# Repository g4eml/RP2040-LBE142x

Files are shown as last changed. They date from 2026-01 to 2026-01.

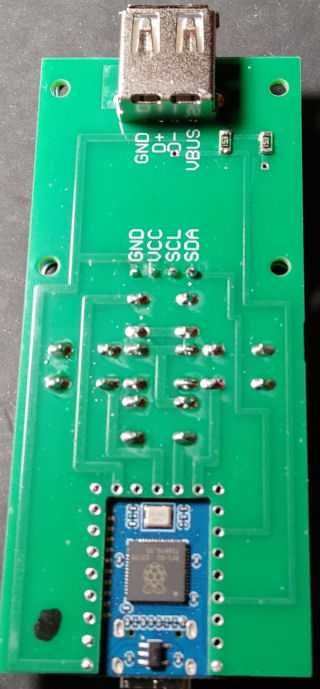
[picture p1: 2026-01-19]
BottomView.jpg

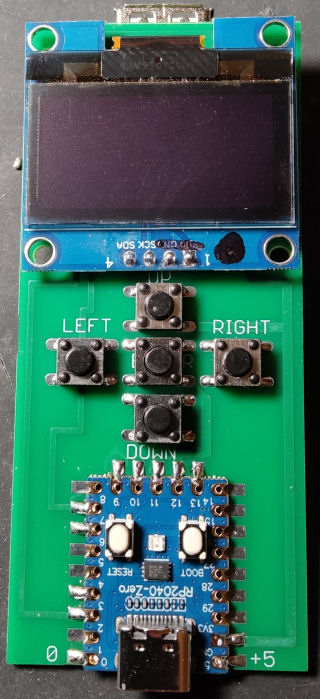
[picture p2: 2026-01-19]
TopView.jpg

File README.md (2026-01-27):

# RP2040_LBE142x

## Description

Stand alone programmer for the Leo Bodner LBE-1420 and LBE-1421 GPSDOs. 

## Features

Connects to LBE-1420 or LBE-1421 using USB. Allows the current frequencies of the unit to be changed without needing to be connected to a computer. 

100 memories to store regularly used frequencies. 

OLED display to show current frequency and memory contents. 

Memories can be changed using the 5 menu buttons. 

## Requirements

RP2040 Zero Module.  (other RP2040 modules can also be used, such as the Pico)

1.3" I2C OLED display (4 Pin type).  128 x 64 pixels single colour. Available from many sources. Try to get one with the SH1106 Controller chip.

**Warning...** These displays come from various manufacturers. There does not seem to be any standard for the pin layout. Check the VCC and GND pins match the PCB layout. 
Some versions of the display have configuration jumpers to swap the VCC and Ground Pins. Configure these so that Pin 1 is GND and Pin 2 is VCC. 

5 push button switches. (Tactile switches)

USB A PCB Mount Socket. 

2 15K resistors

## Construction

A PCB Design is included. The gerber files can be sent to any of the low cost PCB manufacturers. 

Note that the USB-A socket and the two 15K resistors are fitted on the bottom side of the PCB. The RP2040 Zero, Buttons and Display are all fitted on the top side. Make sure you fit the USB-A socket before the Display. 

Alternatively the design can easily be built on matrix board. 

This is the schematic. 

[Schematic.pdf](https://github.com/g4eml/RP2040-LBE142x/blob/main/Schematic.pdf)

Top View.
[Top View](https://github.com/g4eml/RP2040-LBE142x/blob/main/TopView.jpg)

Bottom View.
[Bottom View](https://github.com/g4eml/RP2040-LBE142x/blob/main/BottomView.jpg)

## Enclosure

A 3d printable enclosure is included in the 3D Print folder.  This consists of three parts, the main box, the endcap and the pushbuttons. Note that the holes in the main box are deliberately printed undersize. These need to be drilled out to 5mm diameter. This produces
neater holes than trying to print them directly. The display window can be cut out with a sharp knife. The pushbuttons should be left connected together, do not cut them apart.

## Programming or updating the RP2040 Zero Module (quick method)

1. Locate the latest compiled firmware file 'RP2040_LBE142x.uf2' which will be found here https://github.com/g4eml/RP2040-LBE142x/releases and save it to your desktop. 

2. Connect the Module to your PC using the USB-C port.. 

3. Hold down the BOOT button on the HMI module and briefly press the Reset button. The RP2040 should appear as a USB disk drive on your PC.

3. Copy the .uf2 file onto the USB drive. The RP2040 will recognise the file and immediately update its firmware and reboot.

## Building your own version of the firmware (longer method and not normally required)

The RP2040 is programmed using the Arduino IDE with the Earl F. Philhower, III  RP2040 core. 

#### Installing the Arduino IDE

1. Download and Install the Arduino IDE 2.3.0 from here https://www.arduino.cc/en/software

2. Open the Arduino IDE and go to File/Preferences.

3. in the dialog enter the following URL in the 'Additional Boards Manager URLs' field: https://github.com/earlephilhower/arduino-pico/releases/download/global/package_rp2040_index.json

4. Hit OK to close the Dialog.

5. Go to Tools->Board->Board Manager in the IDE.

6. Type “RP2040” in the search box.

7. Locate the entry for 'Raspberry Pi Pico/RP2040 by Earle F. Philhower, III' and click 'Install'

### Installing the required libraries

1. From the Arduino IDE select (Tools > Manage Libraries)
2. Search for 'Adafruit GFX' Scroll down to find the Adafruit GFX Library by Adafruit.
3. Click Install
4. Now search for 'Adafruit SH110X' and find the Adafruit SH110X library by Adafruit..
5. Click Install

#### Downloading the Software.

1. Download the latest released source code .zip file from https://github.com/g4eml/RP2040_LBE142x/releases

2. Save it to a convenient location and then unzip it.

#### Programming the RP2040

1. Open the Arduino IDE and click File/Open

2. Navigate to the File RP2404Synth/RP2040_LBE1421x.ino (downloaded in the previous step) and click Open.

3. Select Tools and make the following settings.

   Board: "Raspberry Pi Pico"
   
   Debug Level: "None"

   Debug Port: "Disabled"

   C++ Exceptions: "Disabled"

   Flash Size: "2Mb (no FS)"

   CPU Speed: "240MHz (Overclock)"   ........ Note the USB Host Mode only works with multiples of 120MHz for the clock. 240 MHz seems to work OK on most chips. 

   IP/Bluetooth Stack: "IPV4 Only"

   Optimise: "Small (-Os)(standard)"

   RTTI: "Disabled"

   Stack Protection: "Disabled"

   Upload Method: "Default (UF2)"

   USB Stack: "Adafruit TinyUSB"  

5. Connect the RP2040 Module to the USB port, hold down the BOOT button and briefly press the reset Button. 

6. Click Sketch/Upload.

The Sketch should compile and upload automatically to the RP2040. If the upload fails you may need to disconnect the module and then hold down the BOOT button while reconnecting. 

## Firmware description

When power is applied to the RP2040 USB-C socket the firmware will start and display "LBE-1420 Programmer  G4EML 2026"

Connect the LBE-142x to the USB A socket on the programmer.  After a few seconds it should be recognised and the display will show "LBE-1420 Connected" , the current Frequencies and the GPS Lock Status. 

To change the frequency press the Enter button. 
A new line will appear at the bottom of the display. " M00=  10.000000 MHz "  (note that on first use all memories will be initialised to 10.000000 MHz.)
The M00 part of the line will be underlined, indicating the Memory number can be changed. Do this with the Up or down buttons.
When connected to a LBE-1421 each press of the up or down button will cycle between F1 and F2 before changing the memory number. 
When you have selected the memory you require press the Enter button. The memory frequency will be transfered to the LBE-142x and the status lines at the top of the screen should show it has been accepted. 

To change the memory frequencies. 
Fist select the required memory using the Up and down bottons. 
For the LBE-1421 make sure you have also selected the correct output. 
Then press the right button to move the underline cursor to the first of the frequency digits (1000 Mhz).
Position the cursor on the required digit using the left and right buttons.
Change the digit using the Up and Down buttons. 
When you have selected the frequency you require press the Enter button. 
The frequency will be transfered to the LBE-142x and will also be saved to the RP2040 EEPROM for future use.

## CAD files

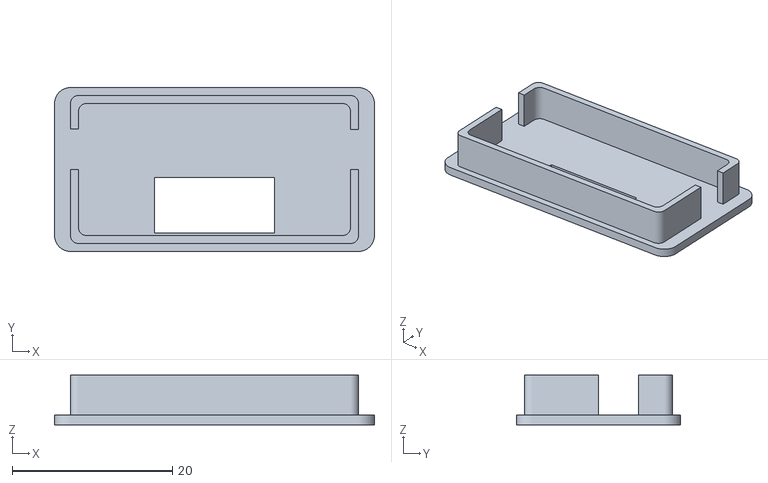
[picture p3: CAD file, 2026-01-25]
3D Print/V2/EndCap-Plus1.stl
40.0 x 20.5 x 6.19

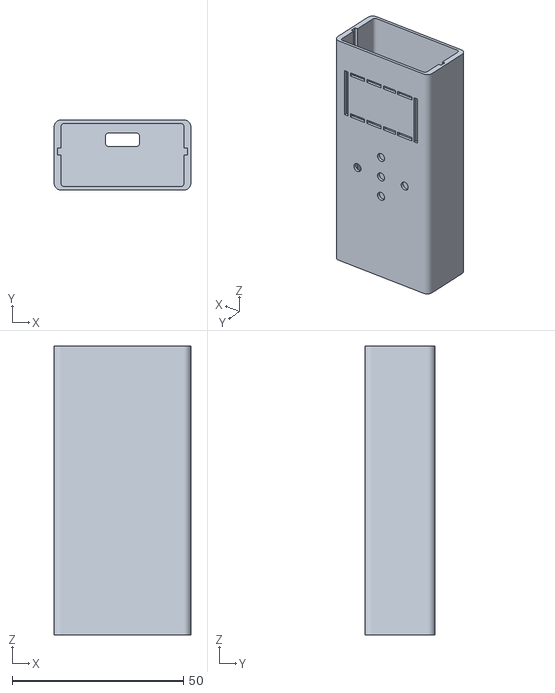
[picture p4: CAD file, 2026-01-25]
3D Print/V2/Box-Plus1.stl
40.0 x 20.5 x 84.5

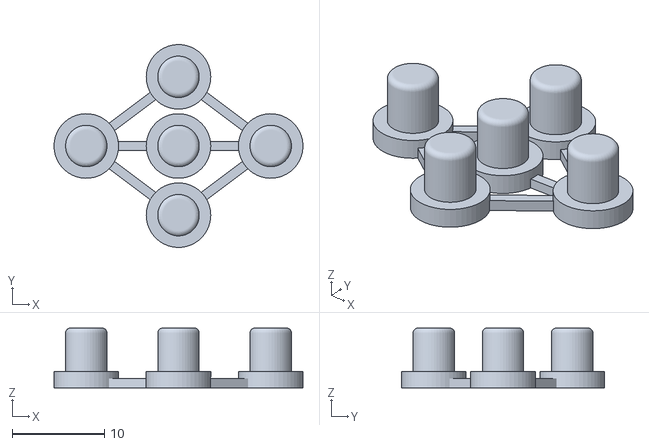
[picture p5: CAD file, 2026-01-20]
3D Print/V2/Buttons.stl
27.0 x 22.0 x 6.50

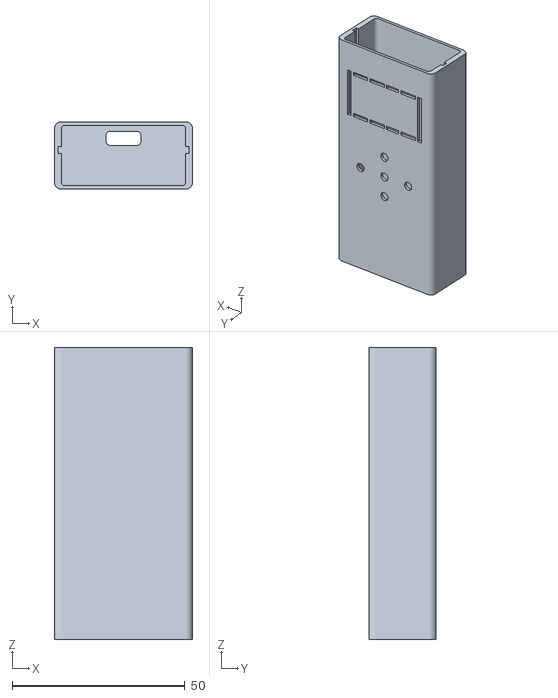
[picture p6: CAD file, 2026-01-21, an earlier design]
3D Print/V1/Box.stl
40.0 x 19.5 x 84.5

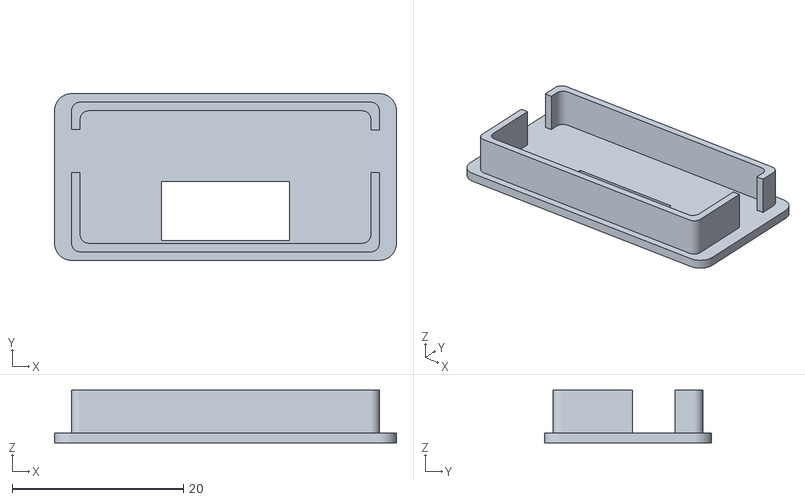
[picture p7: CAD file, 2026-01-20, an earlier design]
3D Print/V1/EndCap.stl
40.0 x 19.5 x 6.19

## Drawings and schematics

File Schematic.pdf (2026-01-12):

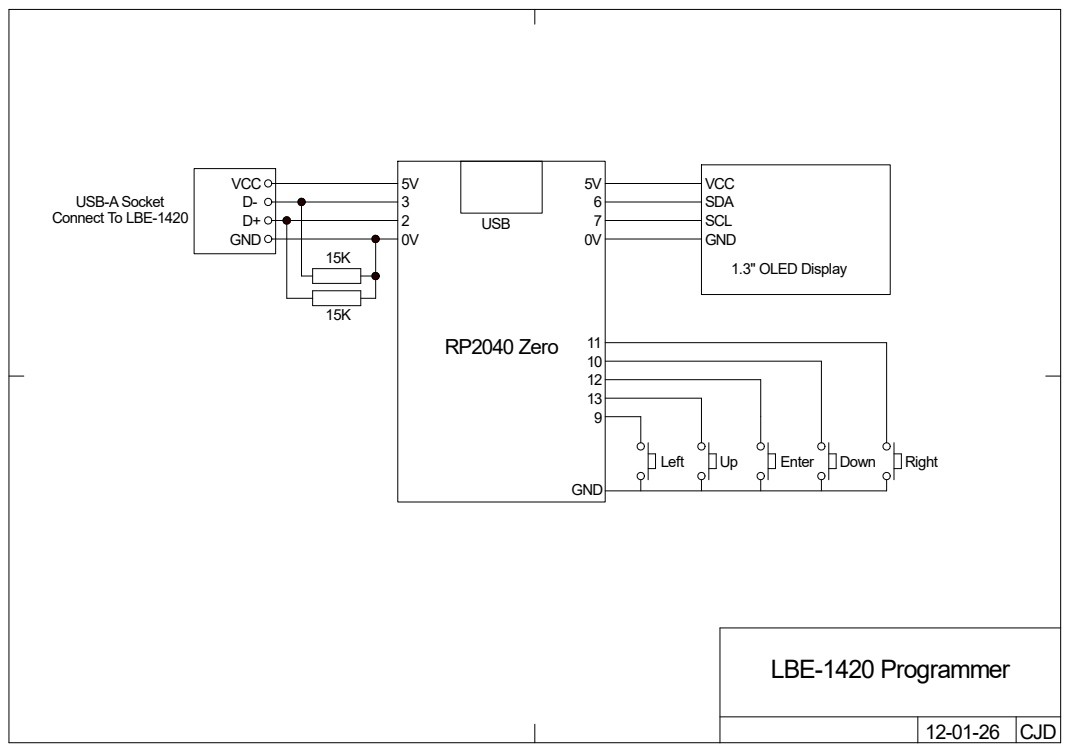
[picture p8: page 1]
LBE-1420 Programmer; CJD; RP2040 Zero; GND; Left; USB; Enter; Down; Right; VCC; SDA SCL; 1.3" OLED Display

USB-A Socket
Connect To LBE-1420

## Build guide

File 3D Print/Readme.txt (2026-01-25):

The 3D desiigns have 2 versions.
The V1 Version is the original prototype.  
The V2 Version has an increase gap between the buttons and the front of the case. 
This extra clearance may be needed for some button types to ensure sufficient clearance.

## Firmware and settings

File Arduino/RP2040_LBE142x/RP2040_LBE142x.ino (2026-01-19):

//Leo Bodner LBE-1420 Programmer
//
//  ***** Important... the PIO-USB library must run at a multiple of 120MHz. 240Mhz overclock is recommended. 
//
// DP+ and Dp- must be pulled to ground with 15K resistors. 
//

#include <Arduino.h>
#include <Wire.h>
#include <EEPROM.h>
#include "pio_usb.h"
#include "pico/platform.h"
#include <Adafruit_GFX.h>
#include "Adafruit_TinyUSB.h"

//two alternative display chips
#define SH1106
//#define SSD1306

#ifdef SSD1306
#include <Adafruit_SSD1306.h>
#endif

#ifdef SH1106
#include <Adafruit_SH110X.h>
#endif

#define I2CADD 0x3C       //DISPLAY i2c Address
//#define I2CADD 0x78

#define HOST_PIN_DP   2   // Pin used as D+ for host, D- on next sequential pin.

#define I2CSDAPin 6
#define I2CSCLPin 7

//Switches for PCB Version

#define UpPin 13
#define DownPin 10
#define LeftPin 9
#define RightPin 11
#define EnterPin 12

#define INVERTSCREEN             

//Switches for Dev Version

// #define UpPin 10
// #define DownPin 13
// #define LeftPin 9
// #define RightPin 12
// #define EnterPin 11



enum buttons {NONE,UP,DOWN,LEFT,RIGHT,ENTER};

uint8_t button;

// TinyUSB Host object
Adafruit_USBH_Host USBHost;

//OLED Display
#ifdef SSD1306
Adafruit_SSD1306 display(128,64,&Wire1,-1);
#endif
#ifdef SH1106
Adafruit_SH1106G display=Adafruit_SH1106G(128,64,&Wire1,-1);
#endif

// =======================
// USB IDs
// =======================
#define LBE_VID        0x1DD2
#define LBE_1420_PID   0x2443
#define LBE_1421_PID   0x2444

#define MINFREQ 1
#define MAXFREQ 1600000000

// =======================
// HID / Protocol
// =======================
#define REPORT_SIZE 60

#define CMD_SET_OUTPUT_EN        0x01     //01 00 sets outputs off   01 FF sets outputs on
#define CMD_BLINK_LEDS           0x02     //02 00 will cause the leds to blink for a few seconds
#define CMD_SET_FREQ_TEMP_1420   0x03     //03 f0 f1 f2 f3      send 4 byte integer representing the frequency in Hz f0 is LSB F3 is MSB. Frequency is temporary and not stored 
#define CMD_SET_FREQ_1420        0x04     //04 f0 f1 f2 f3      send 4 byte integer representing the frequency in Hz f0 is LSB F3 is MSB. Frequency is stored
#define CMD_SET_FREQ1_TEMP       0x05     //05 00 d0 d1 d2 f0 f1 f2 f3     Frequency1 in Hz. d is fractional part MOD 16777216   f is integer part. Temporary
#define CMD_SET_FREQ1            0x06     //06 00 d0 d1 d2 f0 f1 f2 f3     Frequency1 in Hz. d is fractional part MOD 16777216   f is integer part. Stored
#define CMD_SET_SATS             0x07     //07 nn     where nn is bitmap for sats enabled. 0x01=GPS 0x02=SBAS 0x04=Galileo 0x08=Beideo 0x40=GLONASS 
#define CMD_SET_MODE             0x09     //09 nn     where nn is the mode  00=Portable 02=Stationary 08=Airbourne 

#define CMD_SET_FREQ2_TEMP       0x09     //Not Confirmed
#define CMD_SET_FREQ2            0x0A     //Not Confirmed

#define CMD_SET_PLL_FLL          0x0B     //0B nn     where nn =00 is Phase Locked Loop    nn = 01 is Frequency Locked Loop
#define CMD_SET_PPS              0x0C     //Unconfirmed
#define CMD_SET_POWER1           0x0D     //0D 00       Set output power  00 = high power 01=low power
#define CMD_SET_POWER2           0x0E     //Unconfirmed

#define CMD_STATUS               0x4B     //used to request a status message


// =======================
// Globals
// =======================
uint8_t lbe_dev_addr = 0;
uint8_t lbe_instance = 0;
bool lbe_connected = false;
bool lbe1421 = false;

long lastStatusTime =0;
#define NUMBEROFMEMS 100
uint32_t memory[NUMBEROFMEMS]= {10000000};

uint8_t status_buf[REPORT_SIZE];
volatile bool status_ready = false;

uint8_t send_buf[REPORT_SIZE];
volatile bool send_busy = false;

struct LBEStatus 
{
  bool gps_lock;
  bool pll_lock;
  bool antenna_ok;
  bool output_enabled;
  uint32_t frequency;
  uint32_t freqdecimal;
  uint32_t frequency2;
  uint32_t freq2decimal;
};

LBEStatus lbe_status;



void setup1()
{
  // Initialize PIO USB host
  pio_usb_configuration_t pio_cfg = PIO_USB_DEFAULT_CONFIG;
  pio_cfg.pin_dp = HOST_PIN_DP;
  USBHost.configure_pio_usb(1, &pio_cfg);
  // Start TinyUSB host
  USBHost.begin(1);
}

void loop1()
{
  // TinyUSB host task must run all the time so we will dedicate this core to just do that.
  USBHost.task();
}

void setup()
{
  Serial.begin(115200);
  EEPROM.begin(512);
  
  Wire1.setSDA(I2CSDAPin);
  Wire1.setSCL(I2CSCLPin);

#ifdef SSD1306
  display.begin(SSD1306_SWITCHCAPVCC, I2CADD);
#endif
#ifdef SH1106
  display.begin(I2CADD);  
#endif

  pinMode(UpPin,INPUT_PULLUP);
  pinMode(DownPin,INPUT_PULLUP);
  pinMode(LeftPin,INPUT_PULLUP);
  pinMode(RightPin,INPUT_PULLUP);
  pinMode(EnterPin,INPUT_PULLUP);

  readSettings();
#ifdef INVERTSCREEN
  display.setRotation(2);
#endif
  display.clearDisplay();   // clears the screen and buffer
  display.setTextSize(0);
  display.setTextColor(1);
  display.setCursor(10,20);
  display.print("LBE-1420 Programmer");
  display.setCursor(35,40);
  display.print("G4EML 2026");
  display.display();
}

void loop()
{
  uint32_t val;
  static uint32_t lastFreq = 0;
  static uint32_t lastFreq2 = 0;
  static bool lastGPS = 1;
  static bool noPress = false;

  //request status every 5 seconds while device connected. 
  if((millis() > lastStatusTime + 5000) && (lastFreq !=0))
   {
    lastStatusTime = millis();
    lbeRequestStatus();
   }

  // Handle received status
  if (status_ready)
  {
    status_ready = false;
    if((lbe_status.frequency != lastFreq) || (lbe_status.frequency2 != lastFreq2))
    {
    display.setCursor(0,12);
    display.fillRect(0,12,128,8,0);
    if(lbe1421) 
     {
      display.print("F1= ");
     }
     else
     {
      display.print("Freq= ");     
     }
    display.print((double) lbe_status.frequency / 1000000, 6);
    display.print(" MHz");
    lastFreq = lbe_status.frequency;

    if(lbe1421)
     {
       display.setCursor(0,24);
       display.fillRect(0,24,128,8,0);
       display.print("F2= ");
       display.print((double) lbe_status.frequency2 / 1000000, 6);
       display.print(" MHz");
       lastFreq2 = lbe_status.frequency2;
     }
    display.display();
    }

    if(lbe_status.gps_lock != lastGPS)
    {
    display.setCursor(0,24 + 12 * lbe1421);
    display.fillRect(0,24 + 12 * lbe1421,128,8,0);
    display.print("GPS ");
    if(lbe_status.gps_lock == 1)
     {
       display.print("Locked    ");
     }
    else
    {
       display.print("Not Locked");
     }
     lastGPS = lbe_status.gps_lock;
     display.display();
    }
  }
  
  //Process any messages from the other core
  if(rp2040.fifo.available())
  {
    uint32_t msg = rp2040.fifo.pop();
    switch(msg)
    {
      case 1:
      display.clearDisplay();   // clears the screen and buffer
      display.setCursor(0,0);
      display.print("LBE-1420 Connected");
      display.display();
      lbeRequestStatus();
      break;

      case 2:
      display.clearDisplay();   // clears the screen and buffer
      display.setCursor(0,0);
      display.print("LBE-1421 Connected");
      display.display();
      lbeRequestStatus();
      break;

      case 3:
      display.clearDisplay();   // clears the screen and buffer
      display.setCursor(0,0);
      display.print("Device Disconnected");
      display.display();
      lastFreq = 0;
      lastGPS = 1;
      break;
    }
  }

// Handle Button Presses
  if(buttonPressed())
   {
    if(noPress)
     {
       noPress = false;
       processButton();
     }
   }
  else
   {
    noPress = true;
    delay(100);            //debounce delay
   }

}

bool buttonPressed(void)
{
  button = NONE;
  if(digitalRead(UpPin) == 0) button = UP;
  if(digitalRead(DownPin) == 0) button = DOWN;
  if(digitalRead(LeftPin) == 0) button = LEFT; 
  if(digitalRead(RightPin) == 0) button = RIGHT;
  if(digitalRead(EnterPin) == 0) button = ENTER;

  return (button != NONE);
}

void processButton(void)
{
  static uint8_t menuMode = 0;
  enum MM {MOFF,MMEM,MDIG};
  static uint8_t memNumber = 0;
  static uint8_t digitNumber = 0;
  char ml[32];
  static uint32_t increment;
  uint8_t mult;
  static uint8_t channel=1;

    switch(menuMode)
    {
      case MOFF:
       if(button == ENTER)
        {
          menuMode = MMEM;
          sprintf(ml,"M%02d= %11.6f MHz",memNumber , (double) memory[memNumber] / 1000000.0);
          menuLine(ml);
          digitNumber =1;
          setUnderLine(digitNumber);
          if(lbe1421)
           {
            highlight(channel); 
           }
        }

      break;

      case MMEM:
       if(button == ENTER)
        {
          if(lbe1421)
           {
             lbeSetFrequency(channel, memory[memNumber], true);
           }
          else 
          {
            lbeSetFrequency(1, memory[memNumber], true);
          }
          menuMode = MOFF;
          digitNumber =0;
          menuLine("");
          setUnderLine(digitNumber);
          if(lbe1421)
           {
            highlight(0); 
           }
          lastStatusTime = millis() - 4000;    //update the display in 1 second
          break;
        }
       if(button == UP)
        {
          if(lbe1421)
          {
            channel=channel+1;
            if(channel == 3) 
             {
              channel = 1;
              memNumber = (memNumber + 1) % NUMBEROFMEMS;
             }
          }
          else 
          {
             memNumber = (memNumber + 1) % NUMBEROFMEMS;
          }

        }
        if(button == DOWN)
        {
          if(lbe1421)
           {
             channel=channel-1;
             if(channel == 0)
               {
                channel = 2;
                memNumber = (memNumber -1);
                if(memNumber > NUMBEROFMEMS) memNumber = NUMBEROFMEMS - 1;
               }
           }
          else 
           {
                memNumber = (memNumber -1);
                if(memNumber > NUMBEROFMEMS) memNumber = NUMBEROFMEMS - 1;
           }
 
        }   
        if(button == RIGHT)
        {
          digitNumber = 2;
          menuMode = MDIG;
        }    
       sprintf(ml,"M%02d= %11.6f MHz",memNumber , (double) memory[memNumber] / 1000000.0);
       menuLine(ml);
       setUnderLine(digitNumber);
       if(lbe1421)
           {
            highlight(channel); 
           }
       break;

       case MDIG:
       if(button == ENTER)
        {
          if((millis() - lastStatusTime) > 500);
          {
           lbeSetFrequency(1, memory[memNumber], true);
           writeSettings();
           lastStatusTime = millis() - 4500;    //update the display in 0.5 second           
          }
          break;
        }
       if(button == RIGHT)
       {
        digitNumber=digitNumber +1;
        if(digitNumber > 11) digitNumber = 11;
        setUnderLine(digitNumber);
       }
       if(button == LEFT)
       {
        digitNumber = digitNumber - 1;
        if(digitNumber == 1)
         {
          menuMode = MMEM;
         }
        setUnderLine(digitNumber);
       }
       if(button == UP)
       {
        increment = 1;
        mult = 11-digitNumber;
        while(mult > 0)
         {
          increment = increment *10;
          mult--;
         }
        memory[memNumber] = memory[memNumber] +  increment;
        if(memory[memNumber] >= MAXFREQ) memory[memNumber] = MAXFREQ;
        sprintf(ml,"M%02d= %11.6f MHz",memNumber , (double) memory[memNumber] / 1000000.0);
        menuLine(ml);
       }
       if(button == DOWN)
       {
        increment = 1;
        mult = 11-digitNumber;
        while(mult > 0)
         {
          increment = increment *10;
          mult--;
         }
         if(memory[memNumber] > increment)
          {
            memory[memNumber] = memory[memNumber] -  increment;
          } 
          else
          {
            memory[memNumber] = MINFREQ;
          }
        sprintf(ml,"M%02d= %11.6f MHz",memNumber , (double) memory[memNumber] / 1000000.0);
        menuLine(ml);
       }
    }

}

void menuLine(char * txt)
{
    display.setCursor(0,50);
    display.fillRect(0,50,128,8,0);
    display.print(txt);
    display.display();
}

void setUnderLine(uint8_t ul)
{
    display.fillRect(0,60,128,4,0);
    switch(ul)
    {
      case 0:
      break;
      case 1:
        display.fillRect(0 , 60, 18, 4, 1);
      break;
      case 2 ... 5:
        display.fillRect(ul*6 + 18, 60, 6, 4, 1);
      break;
      case 6 ... 11:
        display.fillRect(ul*6 + 24, 60, 6, 4, 1);
      break;
    }
    display.display();
}

void highlight(uint8_t ul)
{
    switch(ul)
    {
      case 0:
      display.fillRect(0,20,12,2,0);
      display.fillRect(0,32,12,2,0);
      break;
      case 1:
      display.fillRect(0,20,12,2,1);
      display.fillRect(0,32,12,2,0);
      break;
      case 2:
      display.fillRect(0,20,12,2,0);
      display.fillRect(0,32,12,2,1);
      break;
    }

    display.display();
}
void readSettings(void)
{
  if(EEPROM.read(0) == 0x73)              //valid EEPROM
   {
    EEPROM.get(1,memory);
   }
  else
   {
     for(int i = 0;i<NUMBEROFMEMS; i++)
      {
        memory[i] = 10000000;
      }
      writeSettings();
   } 
}

void writeSettings(void)
{
  EEPROM.write(0,0x73);
  EEPROM.put(1,memory);
  EEPROM.commit();
}

// =======================
// TinyUSB callbacks
// =======================

// Device mounted
void tuh_hid_mount_cb(uint8_t dev_addr, uint8_t instance, uint8_t const* desc_report, uint16_t desc_len)
{
  uint16_t vid, pid;

  tuh_vid_pid_get(dev_addr, &vid, &pid);

  if (vid == LBE_VID && (pid == LBE_1420_PID || pid == LBE_1421_PID))
  {
    lbe_dev_addr = dev_addr;
    lbe_instance = instance;

    if(pid == LBE_1420_PID)
    {
      rp2040.fifo.push(1);             //signal this event to the other core
      lbe1421=false;
      lbe_connected = true;
    }

    if(pid == LBE_1421_PID)
    {
      rp2040.fifo.push(2);           //signal this event to the other core
      lbe1421=true;
      lbe_connected = true;
    }
  }
}

// Device unmounted
void tuh_hid_umount_cb(uint8_t dev_addr, uint8_t instance)
{
  if (dev_addr == lbe_dev_addr && instance == lbe_instance)
  {
    lbe_connected = false;
    rp2040.fifo.push(3);              //signal this event to the other core
  }
}

// GET_REPORT completed

void tuh_hid_get_report_complete_cb(uint8_t dev_addr, uint8_t idx, uint8_t report_id, uint8_t report_type, uint16_t len)
{
  if (!lbe_connected) return;
  if (dev_addr != lbe_dev_addr || idx != lbe_instance) return;
  if (report_type != HID_REPORT_TYPE_FEATURE) return;
  if (report_id != CMD_STATUS) return;
  if (len < REPORT_SIZE) return;

  // status_buf was filled by TinyUSB
  uint8_t raw = status_buf[1];

  lbe_status.gps_lock       = raw & (1 << 0);
  lbe_status.pll_lock       = raw & (1 << 1);
  lbe_status.antenna_ok     = raw & (1 << 2);
  lbe_status.output_enabled = raw & (1 << 4);

  lbe_status.frequency =status_buf[6] | (status_buf[7] << 8) | (status_buf[8] << 16) | (status_buf[9] << 24);

  lbe_status.freqdecimal = status_buf[3] | (status_buf[4] << 8) | (status_buf[5] << 16);

  if(lbe1421)
   {
      lbe_status.frequency2 =status_buf[14] | (status_buf[15] << 8) | (status_buf[16] << 16) | (status_buf[17] << 24);
      lbe_status.freq2decimal = status_buf[11] | (status_buf[12] << 8) | (status_buf[13] << 16);
   }
  else 
   {
     lbe_status.frequency2 = 0;
     lbe_status.freq2decimal = 0;
   }
  status_ready = true;
}

//=======================
//Low-level helpers
//=======================
bool lbeSendFeature(void)
{
  if (!lbe_connected) return false;  
  send_busy = true;
  bool ok = tuh_hid_set_report(lbe_dev_addr, lbe_instance, 0x00, HID_REPORT_TYPE_FEATURE, send_buf, REPORT_SIZE);
  return ok;
}

void tuh_hid_set_report_complete_cb(uint8_t dev_addr, uint8_t idx, uint8_t report_id, uint8_t report_type, uint16_t len)
{
  send_busy = false;                    //finished with the send buffer
}


bool lbeRequestStatus(void)
{
  if (!lbe_connected) return false;

  memset(status_buf, 0, REPORT_SIZE);
  status_ready = false;

  return tuh_hid_get_report(lbe_dev_addr, lbe_instance, CMD_STATUS, HID_REPORT_TYPE_FEATURE, status_buf, REPORT_SIZE);
}

// =======================
// High-level API
// =======================

void lbeSetFrequency(uint8_t chan, uint32_t freq_hz, bool permanent)
{
  while(send_busy)            //wait until the send buffer is available
  {
    delay(1);
  }

  for(int i=0;i<REPORT_SIZE;i++)
   {
    send_buf[i] = 0;
   }

  if(lbe1421)
  {
    if(chan == 2)
    {
      send_buf[0] = CMD_SET_FREQ2_TEMP;
    }
    else
    {
      send_buf[0] = CMD_SET_FREQ1_TEMP;
    }

  }
  else
  {
    send_buf[0] = CMD_SET_FREQ1_TEMP;  
  }

  if(permanent)
  {
   send_buf[0] = send_buf[0] +1;
  }
  send_buf[1] =  0;       
  send_buf[2] =  0;       //fractional Hz part not currently implemented. 
  send_buf[3] =  0;
  send_buf[4] =  0;
  send_buf[5] = freq_hz & 0xFF;
  send_buf[6] = (freq_hz >> 8) & 0xFF;
  send_buf[7] = (freq_hz >> 16) & 0xFF;
  send_buf[8] = (freq_hz >> 24) & 0xFF;
  lbeSendFeature();
}

void lbeEnableOutput(bool enable)
{
  while(send_busy)            //wait until the send buffer is available
  {
    delay(1);
  }

  for(int i=0;i<REPORT_SIZE;i++)
   {
    send_buf[i] = 0;
   }
  send_buf[0] = CMD_SET_OUTPUT_EN;
  send_buf[1] = enable ? 0xFF : 0x00;
  lbeSendFeature();
}

void lbeSetPower(uint8_t chan, bool low)
{
  while(send_busy)            //wait until the send buffer is available
  {
    delay(1);
  }

  for(int i=0;i<REPORT_SIZE;i++)
   {
    send_buf[i] = 0;
   }

if((lbe1421) && (chan == 2))
  {
    send_buf[0] = CMD_SET_POWER2;
  }
  else
  {
    send_buf[0] = CMD_SET_POWER1;
  }

  send_buf[1] = low;
  lbeSendFeature();
}

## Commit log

2026-01-12 Update README with construction info and schematic link
    Added construction details and schematic link to README.
2026-01-12 Update schematic link in README.md
2026-01-19 Add PCB
    [LBE-1420_Control.GBL, LBE-1420_Control.GBO, LBE-1420_Control.GBP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]
2026-01-19 Enhance README with OLED display warnings and PCB info
    Added warnings and details about the I2C OLED display configuration and PCB design.
2026-01-19 Clarify warning about I2C OLED display pin layout
    Removed redundant warning about display pin layout.
2026-01-19 Fix typo in warning about display pin layout
2026-01-19 Clarify warning about I2C OLED display manufacturers
2026-01-19 Update README with PCB component fitting instructions
    Added note about USB-A socket and component placement.
2026-01-20 Add 3D box
    [Box.stl, Buttons.stl, Endcap.stl]
2026-01-20 Add enclosure details to README
    Added section about the 3D printable enclosure with details on parts and assembly.
2026-01-20 Revise enclosure instructions in README
    Updated instructions for the 3D printable enclosure and added details about cutting the display window.
2026-01-20 Fix capitalization in README enclosure section
2026-01-21 Update 3d model
    [Box.stl]
2026-01-25 Add V2 Box
    [Box-Plus1.stl, Box.stl, Buttons.stl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]
